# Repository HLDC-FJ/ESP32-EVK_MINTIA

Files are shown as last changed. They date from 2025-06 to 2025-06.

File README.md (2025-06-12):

# ESP32 EVK for MINTIA
MINTIA (清涼菓子) ケースを使用し、ESP32 EVK作成を行う。

* ESP32
* Acconeer XM125 (60GHz Radar)
* IR Sensor Array

MINTIAケースを活かし素敵な EVK を作る

このプロジェクトは、ソフトウェアとハードウェアの両方を含みます。
以下のコンポーネントは MIT ライセンスの下で公開されています。

- ソフトウェア（コード、スクリプトなど）
- ハードウェア設計（回路図、基板データ、CADファイルなど）

## ライセンス
このプロジェクトは MIT ライセンスの下で提供されています。  
詳細は [LICENSE](./License.md) ファイルを参照してください。

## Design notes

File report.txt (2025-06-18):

Plotted to 'C:\Proj\CAD\KiCAD\Work\Mini_3_IR\GB\Work-F_Cu.gtl'.
Plotted to 'C:\Proj\CAD\KiCAD\Work\Mini_3_IR\GB\Work-B_Cu.gbl'.
Plotted to 'C:\Proj\CAD\KiCAD\Work\Mini_3_IR\GB\Work-F_Paste.gtp'.
Plotted to 'C:\Proj\CAD\KiCAD\Work\Mini_3_IR\GB\Work-B_Paste.gbp'.
Plotted to 'C:\Proj\CAD\KiCAD\Work\Mini_3_IR\GB\Work-F_Silkscreen.gto'.
Plotted to 'C:\Proj\CAD\KiCAD\Work\Mini_3_IR\GB\Work-B_Silkscreen.gbo'.
Plotted to 'C:\Proj\CAD\KiCAD\Work\Mini_3_IR\GB\Work-F_Mask.gts'.
Plotted to 'C:\Proj\CAD\KiCAD\Work\Mini_3_IR\GB\Work-B_Mask.gbs'.
Plotted to 'C:\Proj\CAD\KiCAD\Work\Mini_3_IR\GB\Work-Edge_Cuts.gm1'.
情報: Done.
情報: Done.

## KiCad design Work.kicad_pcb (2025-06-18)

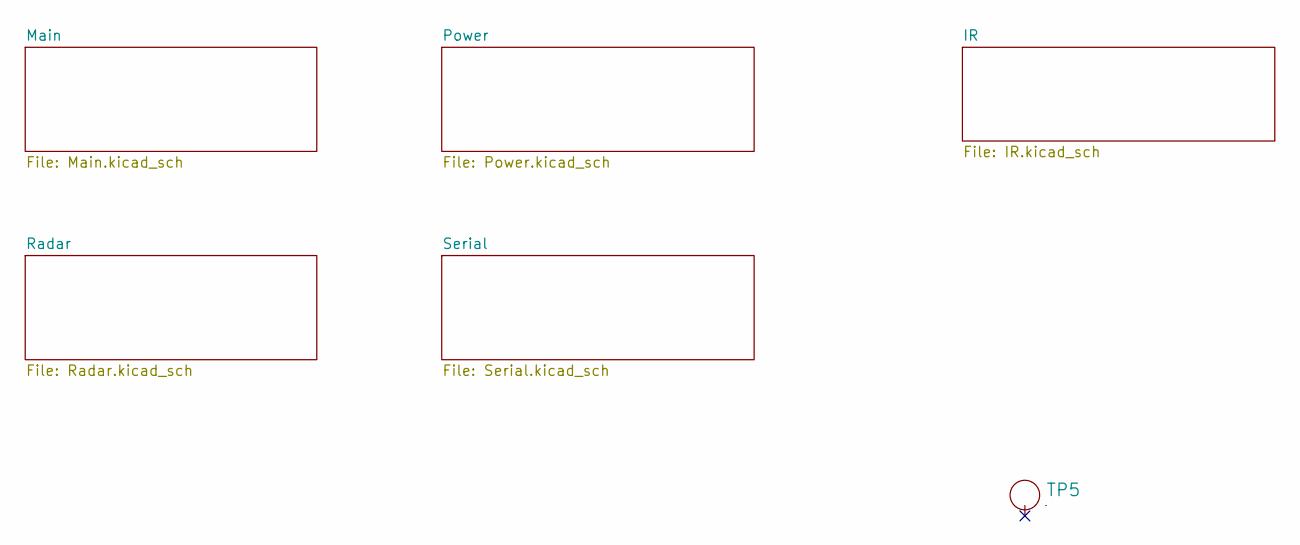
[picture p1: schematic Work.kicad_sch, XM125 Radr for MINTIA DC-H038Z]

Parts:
TP5: TP_FL; HLDC_logo2

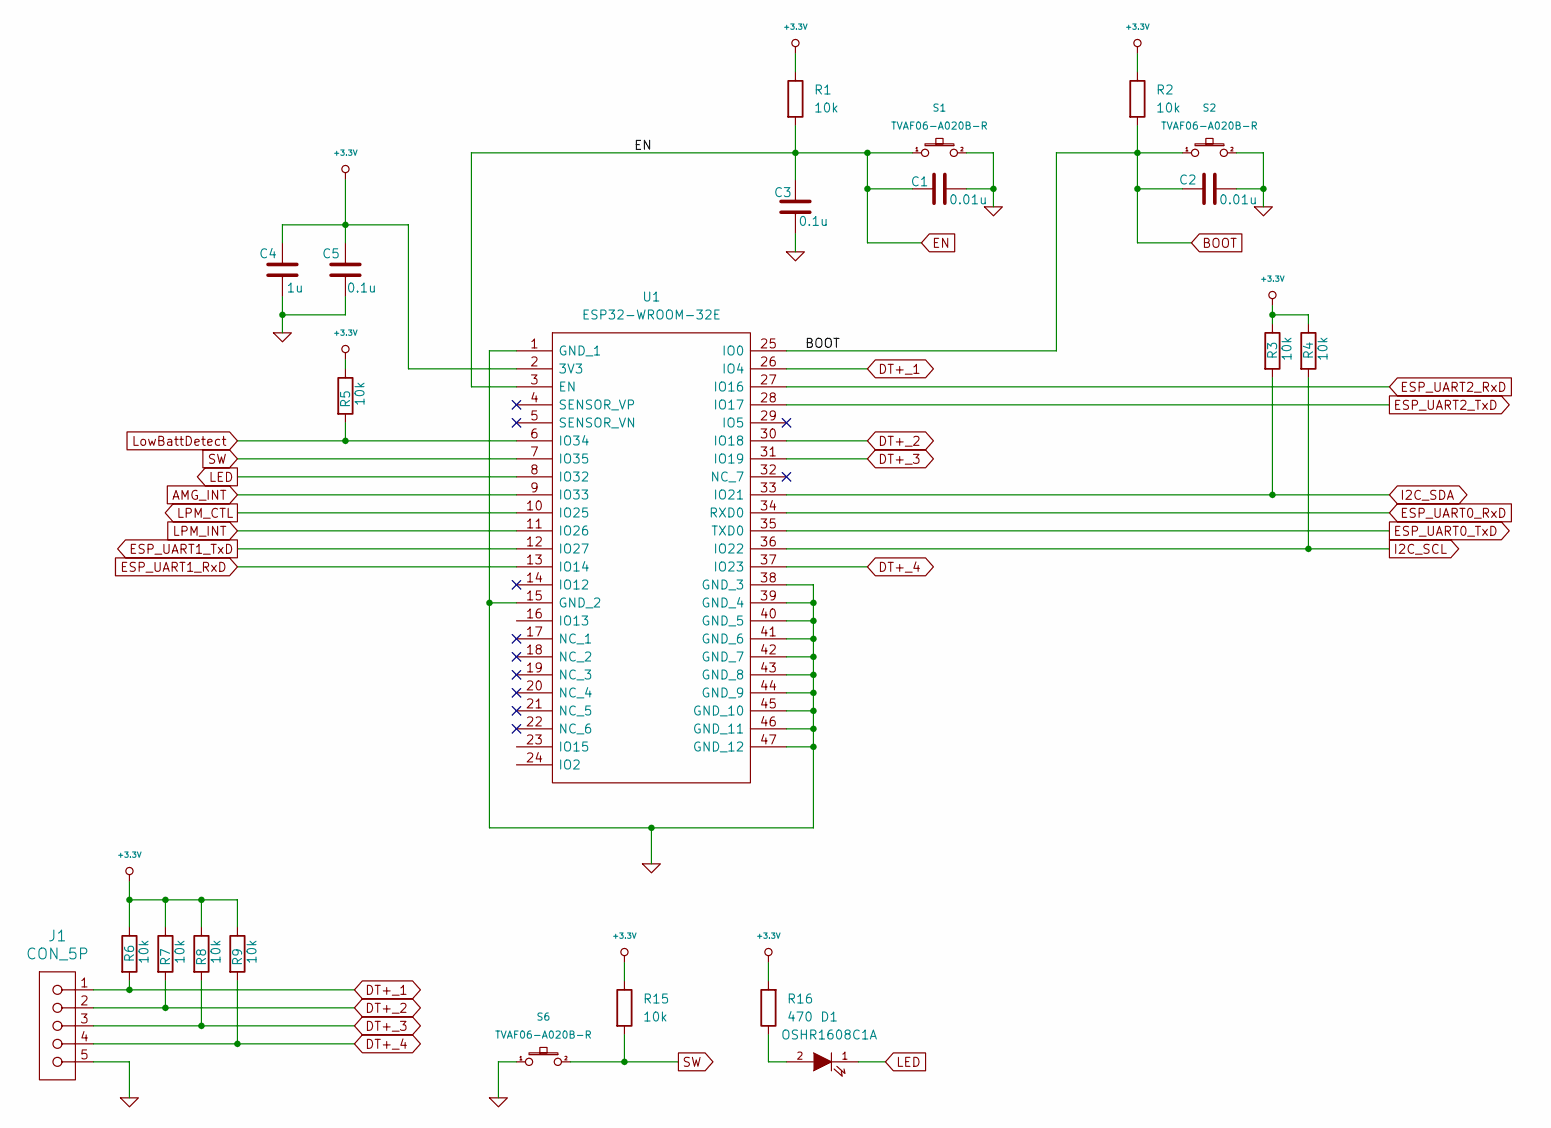
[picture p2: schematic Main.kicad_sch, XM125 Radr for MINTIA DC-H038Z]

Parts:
C1, C2: 0.01u; C_0603_1608Metric; PARTNUMBER GRM1882C1H103JA01
C3, C5: 0.1u; C_0603_1608Metric; PARTNUMBER GRM188R72A104MA35
C4: 1u; C_0603_1608Metric; PARTNUMBER GRM185R61C105KE44
D1: OSHR1608C1A; D_0603; PARTNUMBER OSHR1608C1A
J1: CON_5P; CONN_S5B-ZR_JST; PARTNUMBER S5B-ZR
R1, R2, R3, R4, R5, R6, R7, R8, R9, R15: 10k; R_0603_1608Metric; PARTNUMBER ERJ3GEYJ103V
R16: 470; R_0603_1608Metric; PARTNUMBER ERJ3GEYJ471V
S1, S2, S6: TVAF06-A020B-R; TVAF06A020BR; PARTNUMBER TVAF06-A020B-R
U1: ESP32-WROOM-32E; ESP32WROOM32E-Hole; Manufacturer_Part_Number ESP32-WROOM-32E

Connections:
+3.3V: C4.2, C5.2, R1.1, R2.1, R3.1, R4.1, R5.1, R6.1, R7.1, R8.1, R9.1, R15.1, R16.2, U1.2 (3V3); also elsewhere on the board
AMG_INT: U1.9 (IO33); also elsewhere on the board
BOOT: C2.2, R2.2, S2.1, U1.25 (IO0); also elsewhere on the board
DT+_1: J1.1, R6.2, U1.26 (IO4)
DT+_2: J1.2, R7.2, U1.30 (IO18)
DT+_3: J1.3, R8.2, U1.31 (IO19)
DT+_4: J1.4, R9.2, U1.37 (IO23)
EN: C1.2, C3.1, R1.2, S1.1, U1.3 (EN); also elsewhere on the board
ESP_UART0_RxD: U1.34 (RXD0); also elsewhere on the board
ESP_UART0_TxD: U1.35 (TXD0); also elsewhere on the board
ESP_UART1_RxD: U1.13 (IO14); also elsewhere on the board
ESP_UART1_TxD: U1.12 (IO27); also elsewhere on the board
ESP_UART2_RxD: U1.27 (IO16); also elsewhere on the board
ESP_UART2_TxD: U1.28 (IO17); also elsewhere on the board
GND: C1.1, C2.1, C3.2, C4.1, C5.1, J1.5, S1.2, S2.2, S6.1, U1.1 (GND_1), U1.15 (GND_2), U1.38 (GND_3), U1.39 (GND_4), U1.40 (GND_5), U1.41 (GND_6), U1.42 (GND_7), U1.43 (GND_8), U1.44 (GND_9), U1.45 (GND_10), U1.46 (GND_11), U1.47 (GND_12); also elsewhere on the board
I2C_SCL: R4.2, U1.36 (IO22); also elsewhere on the board
I2C_SDA: R3.2, U1.33 (IO21); also elsewhere on the board
LED: D1.1 (K), U1.8 (IO32)
LPM_CTL: U1.10 (IO25); also elsewhere on the board
LPM_INT: U1.11 (IO26); also elsewhere on the board
LowBattDetect: R5.2, U1.6 (IO34)
unnamed: D1.2 (A), R16.1
SW: R15.2, S6.2, U1.7 (IO35)

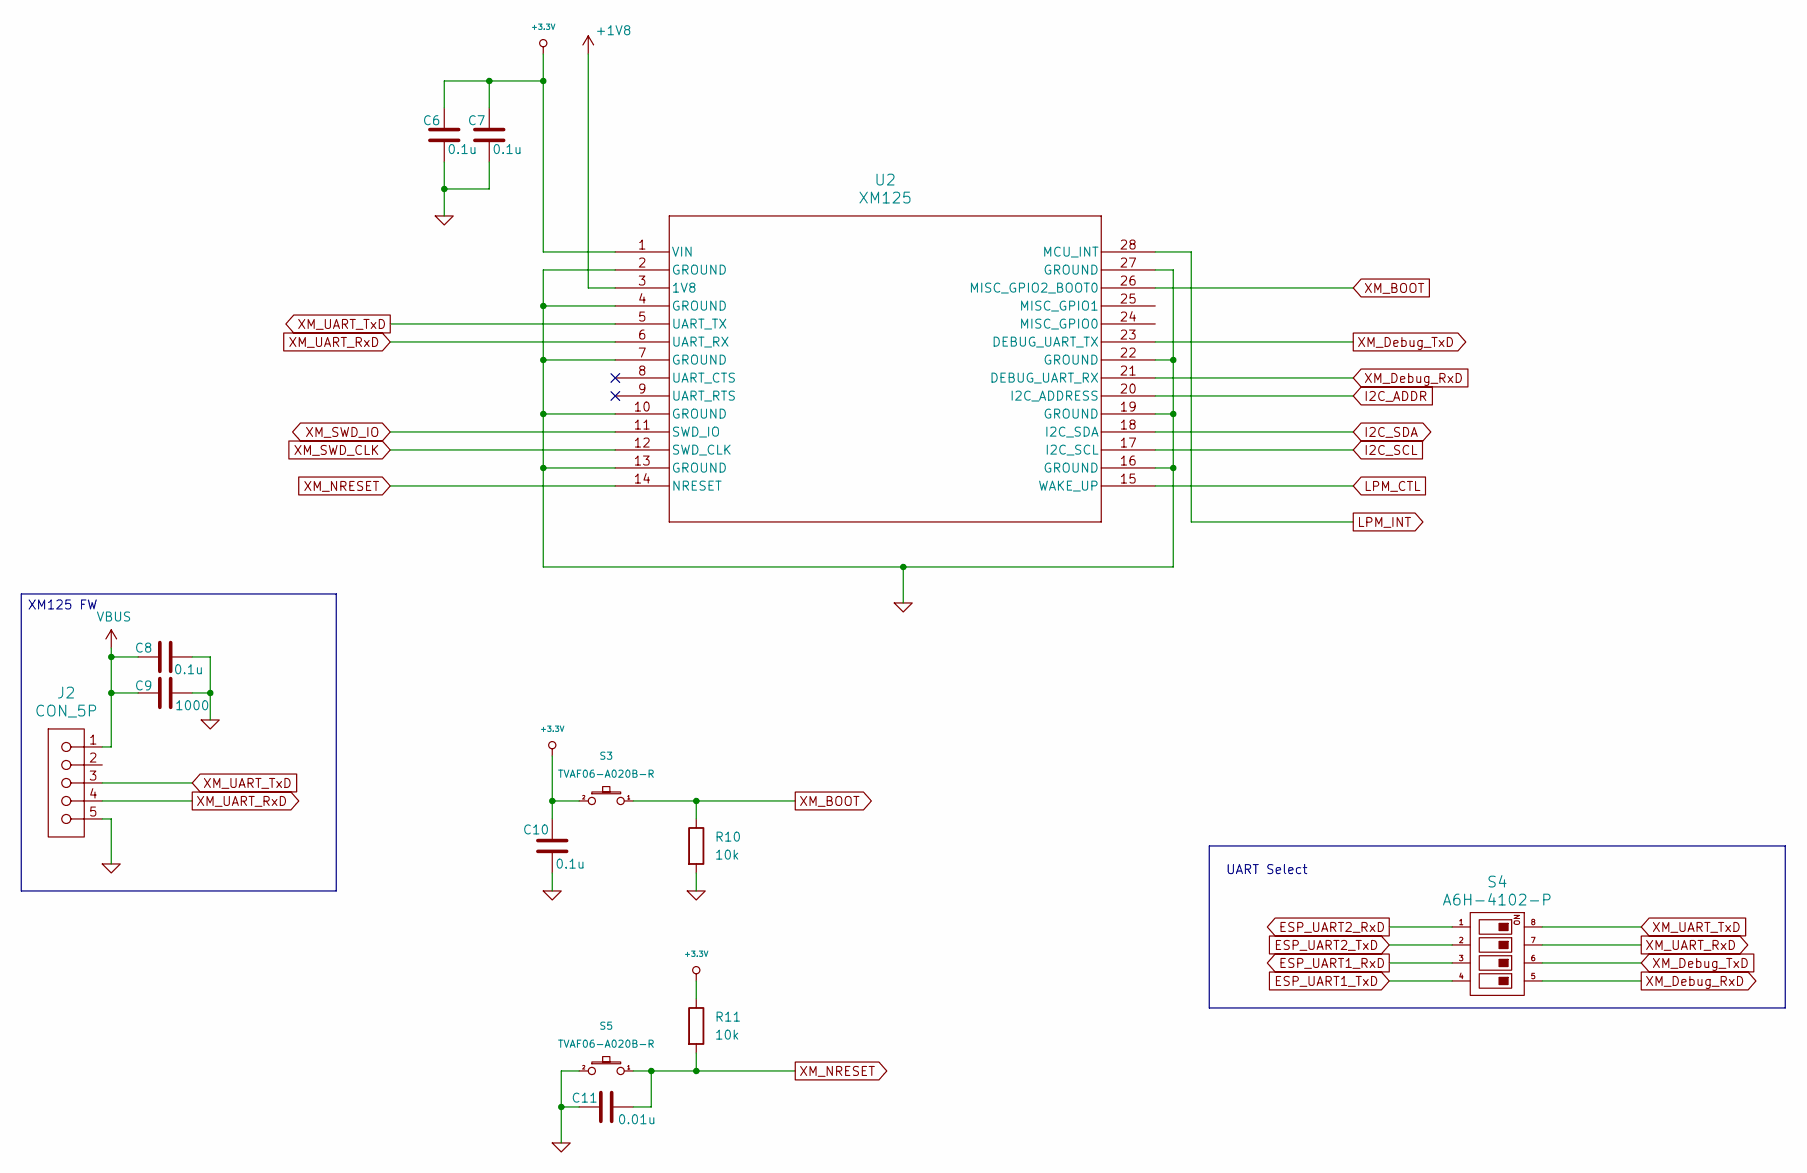
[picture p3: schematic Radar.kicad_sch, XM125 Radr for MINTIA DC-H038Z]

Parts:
C6, C7, C8, C10: 0.1u; C_0603_1608Metric; PARTNUMBER GRM188R72A104MA35
C9: 1000; C_0603_1608Metric; PARTNUMBER GRM1882C1H102JA01
C11: 0.01u; C_0603_1608Metric; PARTNUMBER GRM1882C1H103JA01
J2: CON_5P; CONN_S5B-ZR_JST; PARTNUMBER S5B-ZR
R10, R11: 10k; R_0603_1608Metric; PARTNUMBER ERJ3GEYJ103V
S3, S5: TVAF06-A020B-R; TVAF06A020BR; PARTNUMBER TVAF06-A020B-R
S4: A6H-4102-P; SOIC127P812X230-8N; PARTNUMBER A6H-4102-P
U2: XM125; XM125_ACC; PARTNUMBER XM125

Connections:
+1V8: U2.3 (1V8); also elsewhere on the board
+3.3V: C6.1, C7.1, C10.1, R11.1, S3.2, U2.1 (VIN); also elsewhere on the board
ESP_UART1_RxD: S4.3; also elsewhere on the board
ESP_UART1_TxD: S4.4; also elsewhere on the board
ESP_UART2_RxD: S4.1; also elsewhere on the board
ESP_UART2_TxD: S4.2; also elsewhere on the board
GND: C6.2, C7.2, C8.1, C9.1, C10.2, C11.2, J2.5, R10.2, S5.2, U2.2 (GROUND), U2.4 (GROUND), U2.7 (GROUND), U2.10 (GROUND), U2.13 (GROUND), U2.16 (GROUND), U2.19 (GROUND), U2.22 (GROUND), U2.27 (GROUND); also elsewhere on the board
I2C_ADDR: U2.20 (I2C_ADDRESS)
I2C_SCL: U2.17 (I2C_SCL); also elsewhere on the board
I2C_SDA: U2.18 (I2C_SDA); also elsewhere on the board
LPM_CTL: U2.15 (WAKE_UP); also elsewhere on the board
LPM_INT: U2.28 (MCU_INT); also elsewhere on the board
VBUS: C8.2, C9.2, J2.1; also elsewhere on the board
XM_BOOT: R10.1, S3.1, U2.26 (MISC_GPIO2_BOOT0)
XM_Debug_RxD: S4.5, U2.21 (DEBUG_UART_RX)
XM_Debug_TxD: S4.6, U2.23 (DEBUG_UART_TX)
XM_NRESET: C11.1, R11.2, S5.1, U2.14 (NRESET)
XM_SWD_CLK: U2.12 (SWD_CLK)
XM_SWD_IO: U2.11 (SWD_IO)
XM_UART_RxD: J2.4, S4.7, U2.6 (UART_RX)
XM_UART_TxD: J2.3, S4.8, U2.5 (UART_TX)

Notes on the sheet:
UART Select
XM125 FW

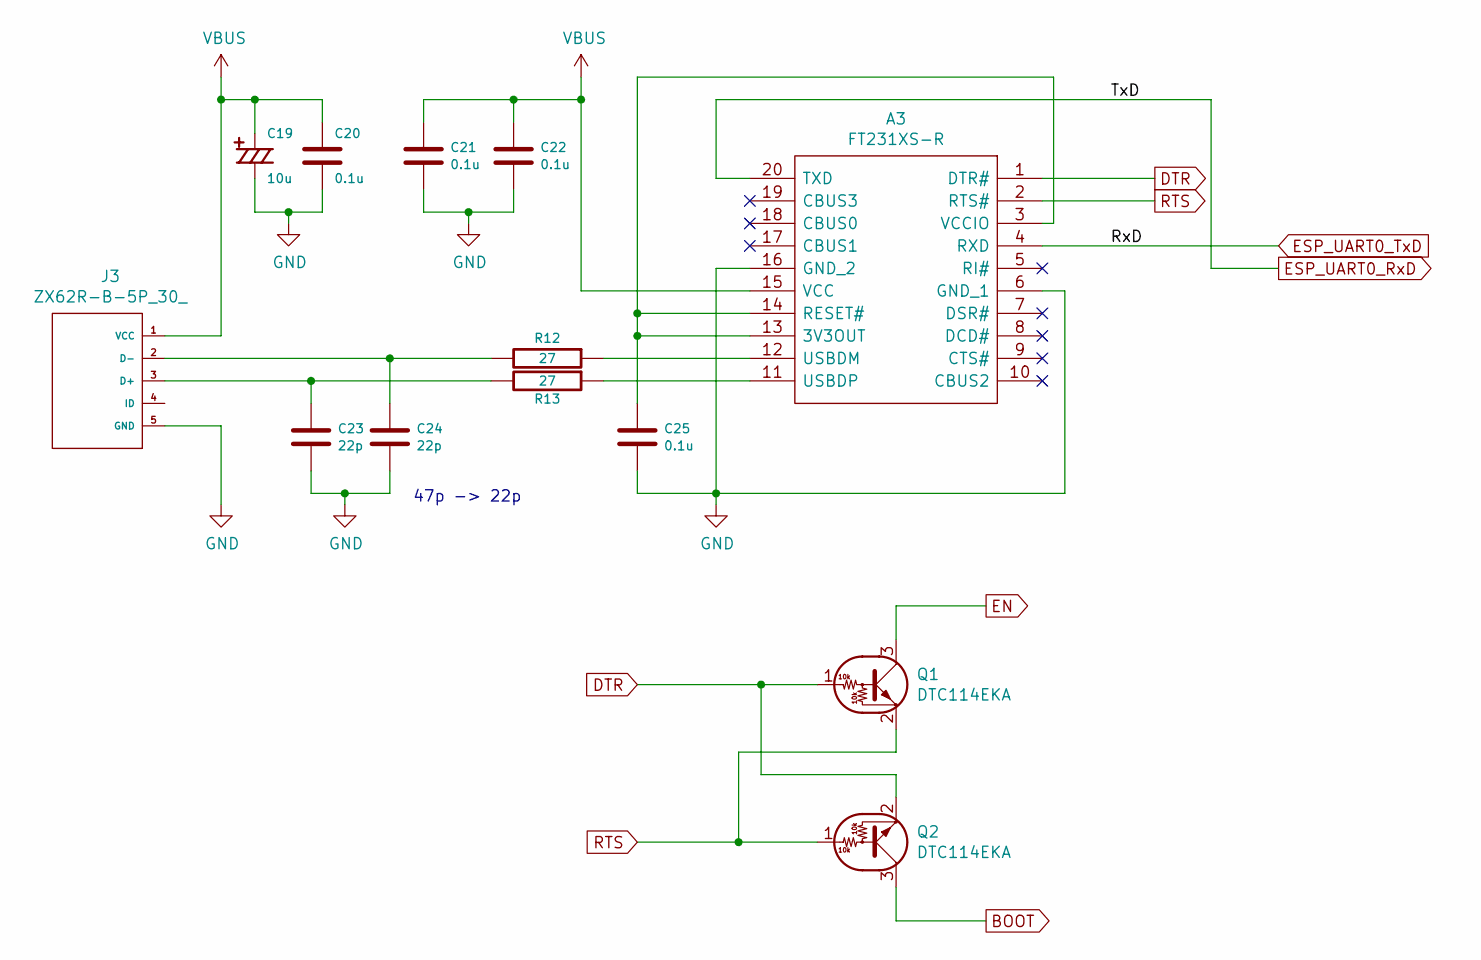
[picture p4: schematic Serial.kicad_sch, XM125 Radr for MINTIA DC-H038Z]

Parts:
A3: FT231XS-R; SOP64P599X175-20N; Manufacturer_Part_Number FT231XS-R
C19: 10u; F920J106MPA; PARTNUMBER F920J106MPA
C20, C21, C22, C25: 0.1u; C_0603_1608Metric; PARTNUMBER GRM188R72A104MA35
C23, C24: 22p; C_0603_1608Metric; PARTNUMBER GRM1885C2E220FW07
J3: ZX62R-B-5P_30_; ZX62R-B-5P_30; PARTNUMBER ZX62R-B-5P(30)
Q1, Q2: DTC114EKA; SC-59; PARTNUMBER DTC114EKA
R12, R13: 27; R_0603_1608Metric; PARTNUMBER ERJ3GEYJ270V

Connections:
BOOT: Q2.3 (C); also elsewhere on the board
DTR: A3.1 (DTR#), Q1.1 (B), Q2.2 (E)
EN: Q1.3 (C); also elsewhere on the board
ESP_UART0_RxD: A3.20 (TXD); also elsewhere on the board
ESP_UART0_TxD: A3.4 (RXD); also elsewhere on the board
GND: A3.6 (GND_1), A3.16 (GND_2), C19.2, C20.2, C21.2, C22.2, C23.2, C24.2, C25.2, J3.5 (GND); also elsewhere on the board
unnamed: A3.3 (VCCIO), A3.13 (3V3OUT), A3.14 (RESET#), C25.1
unnamed: A3.12 (USBDM), R12.1
unnamed: A3.11 (USBDP), R13.1
unnamed: C23.1, J3.3 (D+), R13.2
unnamed: C24.1, J3.2 (D-), R12.2
RTS: A3.2 (RTS#), Q1.2 (E), Q2.1 (B)
VBUS: A3.15 (VCC), C19.1, C20.1, C21.1, C22.1, J3.1 (VCC); also elsewhere on the board

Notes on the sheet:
47p -> 22p

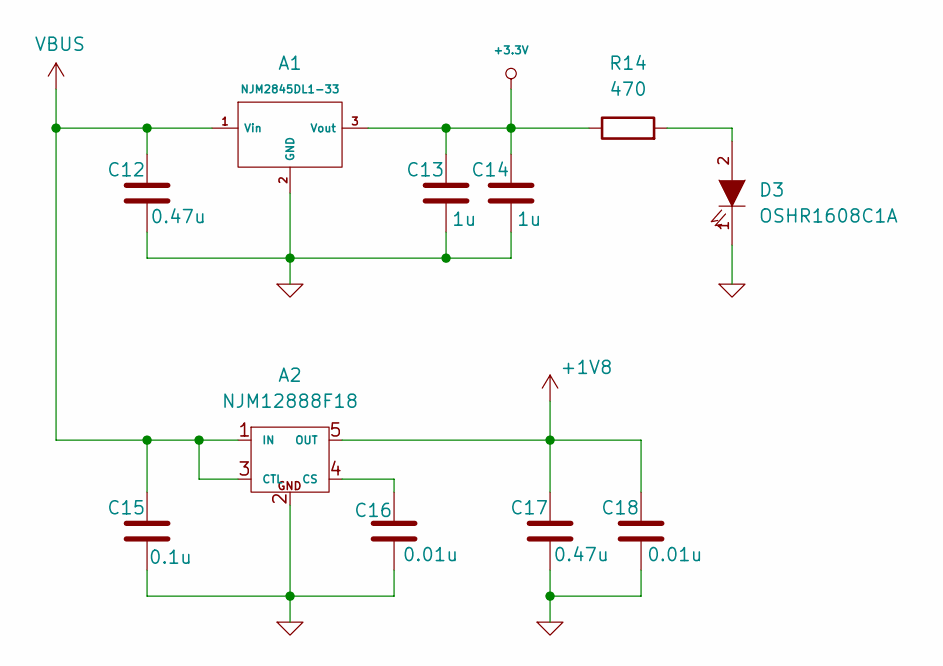
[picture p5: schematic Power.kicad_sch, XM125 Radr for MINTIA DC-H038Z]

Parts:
A1: NJM2845DL1-33; TO-252-2; PARTNUMBER NJM2845DL1-33
A2: NJM12888F18; SOT-23-5; PARTNUMBER NJM12888F18
C12, C17: 0.47u; C_0603_1608Metric; PARTNUMBER GRM188R71C474KA88
C13, C14: 1u; C_0603_1608Metric; PARTNUMBER GRM185R61C105KE44
C15: 0.1u; C_0603_1608Metric; PARTNUMBER GRM188R72A104MA35
C16, C18: 0.01u; C_0603_1608Metric; PARTNUMBER GRM1882C1H103JA01
D3: OSHR1608C1A; D_0603; PARTNUMBER OSHR1608C1A
R14: 470; R_0603_1608Metric; PARTNUMBER ERJ3GEYJ471V

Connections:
+1V8: A2.5 (OUT), C17.2, C18.2; also elsewhere on the board
+3.3V: A1.3 (Vout), C13.2, C14.2, R14.1; also elsewhere on the board
GND: A1.2 (GND), A2.2 (GND), C12.1, C13.1, C14.1, C15.1, C16.1, C17.1, C18.1, D3.1 (K); also elsewhere on the board
unnamed: A2.4 (CS), C16.2
unnamed: D3.2 (A), R14.2
VBUS: A1.1 (Vin), A2.1 (IN), A2.3 (CTL), C12.2, C15.2; also elsewhere on the board

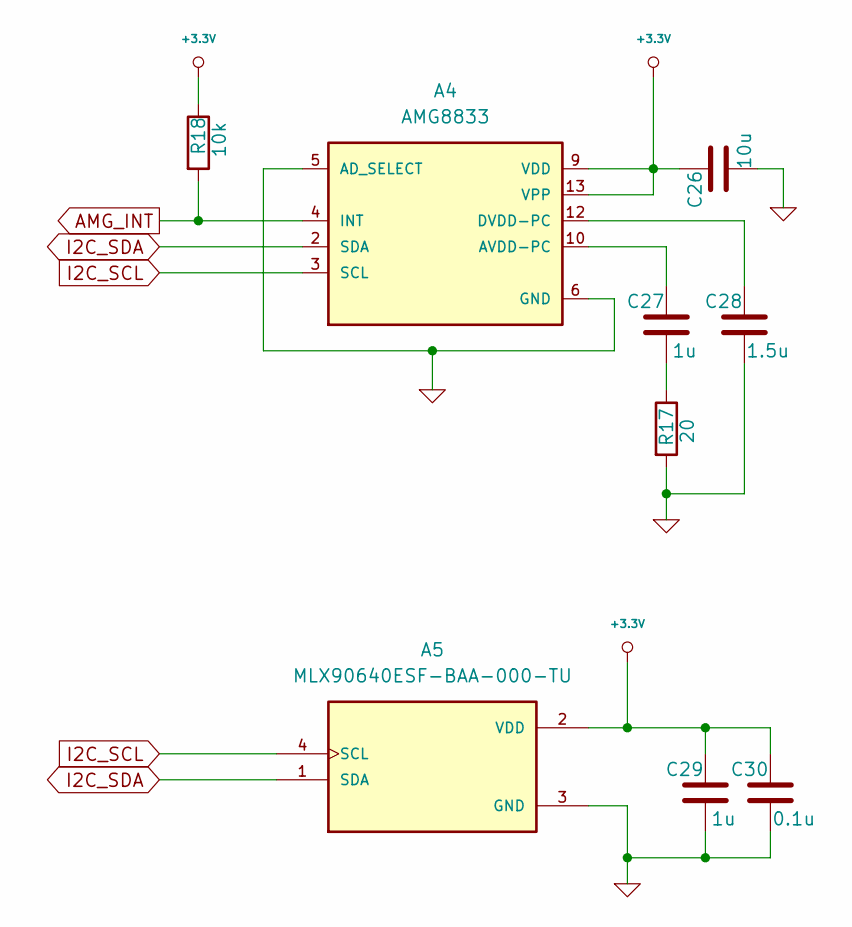
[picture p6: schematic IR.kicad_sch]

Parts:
A4: AMG8833; XDCR_AMG8833; PARTNUMBER AMG8833
A5: MLX90640ESF-BAA-000-TU; TO292P930H600-4; PARTREV 11
C26: 10u; C_0603_1608Metric; PARTNUMBER GRM188C81C106MA73
C27, C29: 1u; C_0603_1608Metric; PARTNUMBER GRM185R61C105KE44
C28: 1.5u; C_0603_1608Metric; PARTNUMBER CGA3E1X5R1C155K080AC
C30: 0.1u; C_0603_1608Metric; PARTNUMBER GRM188R72A104MA35
R17: 20; R_0603_1608Metric; PARTNUMBER ERJ3GEYJ200V
R18: 10k; R_0603_1608Metric; PARTNUMBER ERJ3GEYJ103V

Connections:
+3.3V: A4.9 (VDD), A4.13 (VPP), A5.2 (VDD), C26.2, C29.2, C30.2, R18.1; also elsewhere on the board
AMG_INT: A4.4 (INT), R18.2; also elsewhere on the board
GND: A4.5 (AD_SELECT), A4.6 (GND), A5.3 (GND), C26.1, C28.1, C29.1, C30.1, R17.2; also elsewhere on the board
I2C_SCL: A4.3 (SCL), A5.4 (SCL); also elsewhere on the board
I2C_SDA: A4.2 (SDA), A5.1 (SDA); also elsewhere on the board
unnamed: A4.10 (AVDD-PC), C27.2
unnamed: A4.12 (DVDD-PC), C28.2
unnamed: C27.1, R17.1

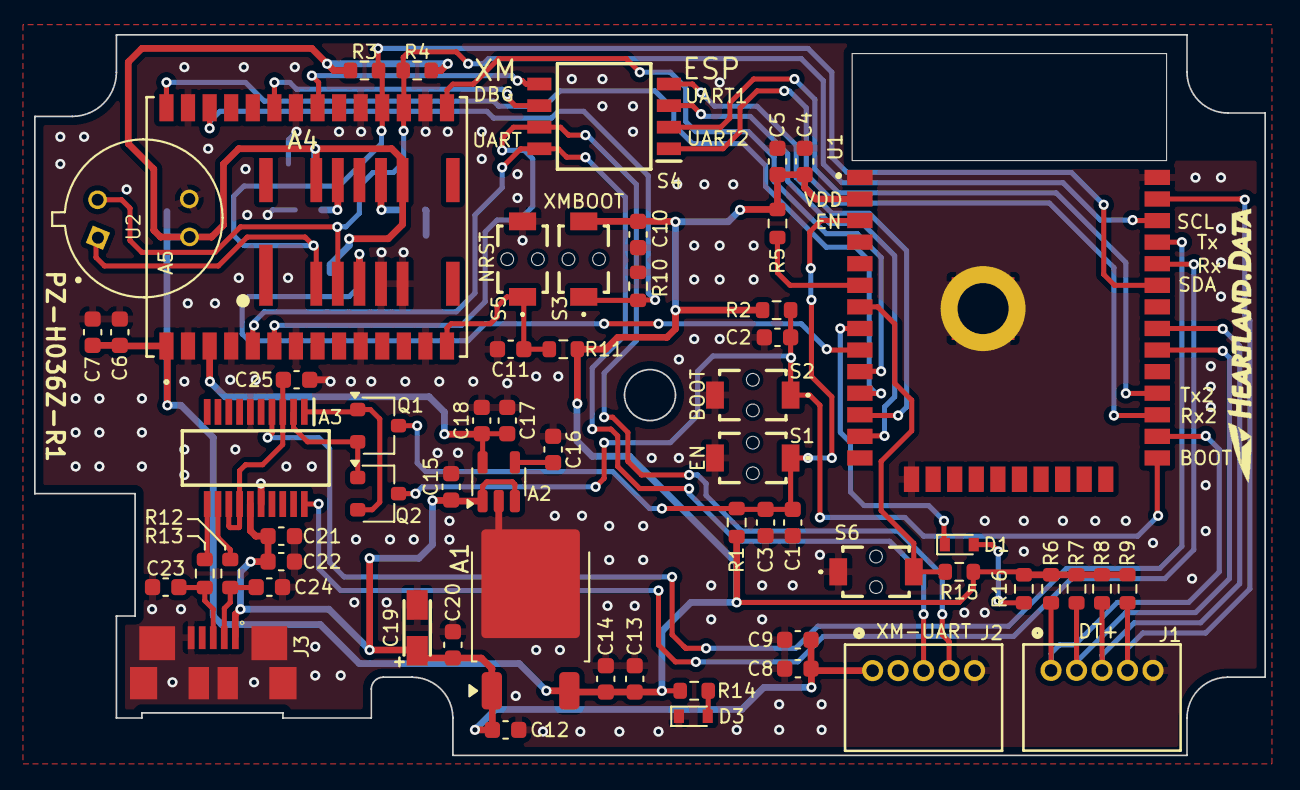
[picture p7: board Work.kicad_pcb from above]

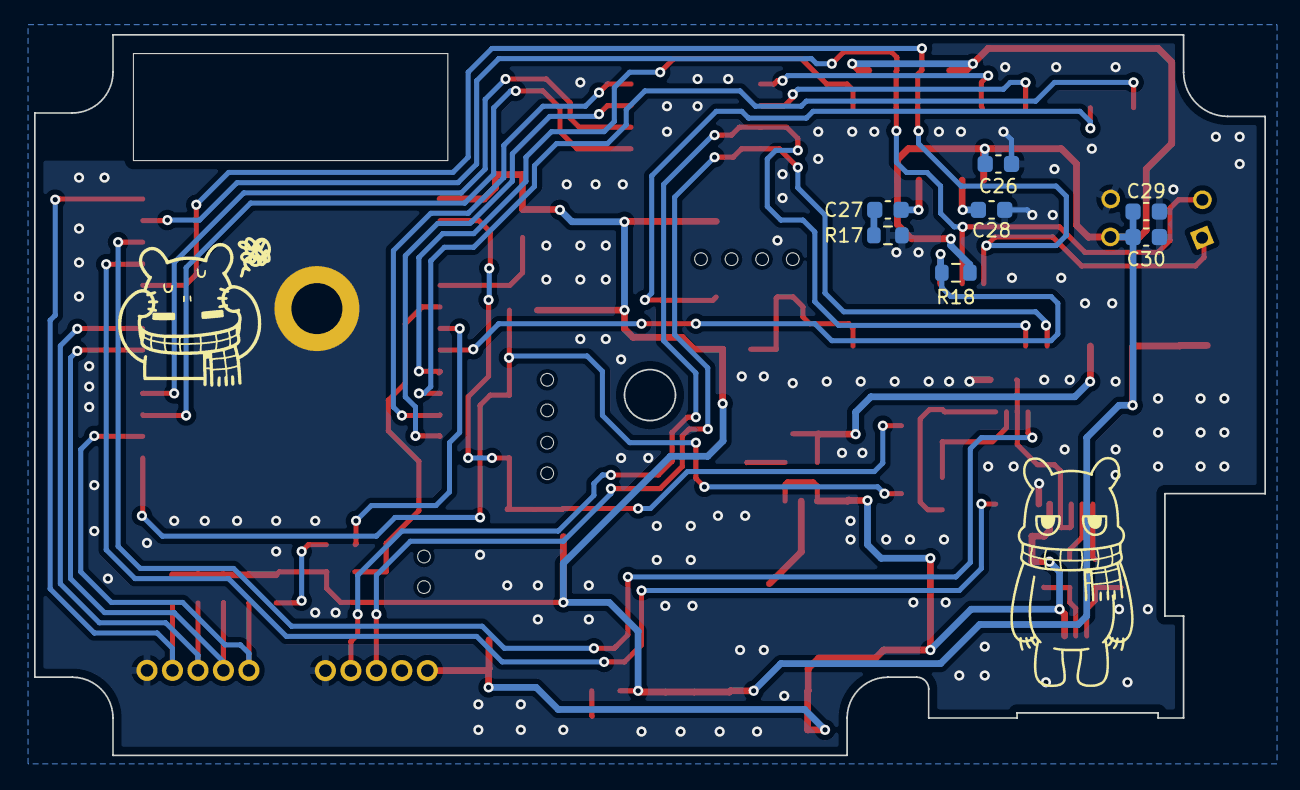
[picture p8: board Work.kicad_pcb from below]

Board: 2 copper layers, 72.4 x 42.4 mm, 69 parts (7 on the bottom side), 43 nets.

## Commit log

2025-06-06 Edge Cut Data
    [Work.kicad_pcb, Work.kicad_sch]
2025-06-09 SCH & PCB Data
    [IR.kicad_sch, Main.kicad_sch, Power.kicad_sch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]
2025-06-18 DIP SW Pad Change
    [Radar.kicad_sch, Work.kicad_pcb]
2025-06-18 Gerber Data
    [PZ-H036Z-R1-B_Cu.gbl, PZ-H036Z-R1-B_Mask.gbs, PZ-H036Z-R1-B_Paste.gbp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]
2025-06-18 Revision change
    [IR.kicad_sch, Main.kicad_sch, Power.kicad_sch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]
